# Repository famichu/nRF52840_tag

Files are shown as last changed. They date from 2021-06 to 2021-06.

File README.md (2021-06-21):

# nRF52840 tag

## What's this?

This is a development board works with coin batteries based on Adafruit Feather nRF52840 Express. This board works on all bootloaders of Adafruit Feather nRF52840 Express.

## Features

- Works with coin battery(CR2032)
- Extra battery(PH connector) support(Not suport charging)
- USB Type-C(USB 2.0)
- Warking same as Adafruit Feather nRF52840 Express(CircuitPython etc)
    - Programmable Full color LED(NeoPIXEL)
    - 1 usable push switch in program
    - 16MBit Flash memory

## How to use

1. Connect j-link and this board via SWD vias back side of this board.
2. Burn a bootloader you want to use with nrfjprog command.
    (For more detail, read "Burninng new Bootloader" on [adafruit's github](https://github.com/adafruit/Adafruit_nRF52_Arduino)

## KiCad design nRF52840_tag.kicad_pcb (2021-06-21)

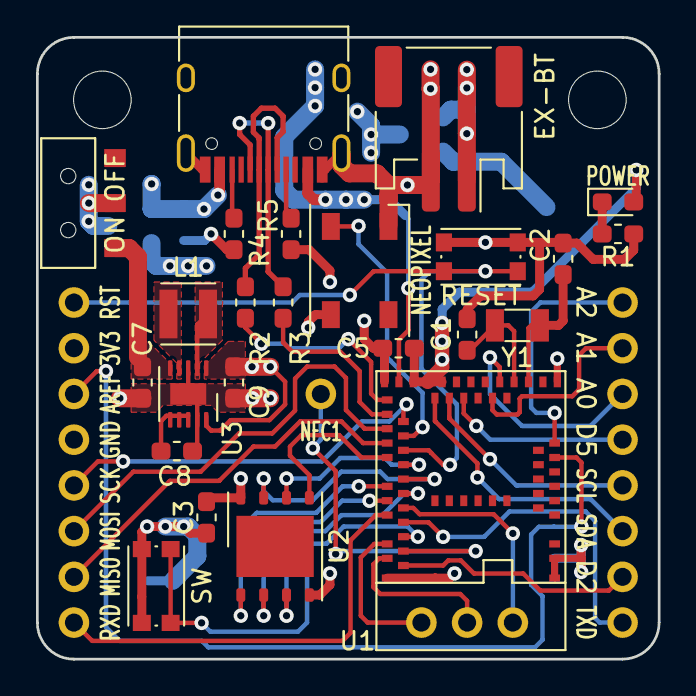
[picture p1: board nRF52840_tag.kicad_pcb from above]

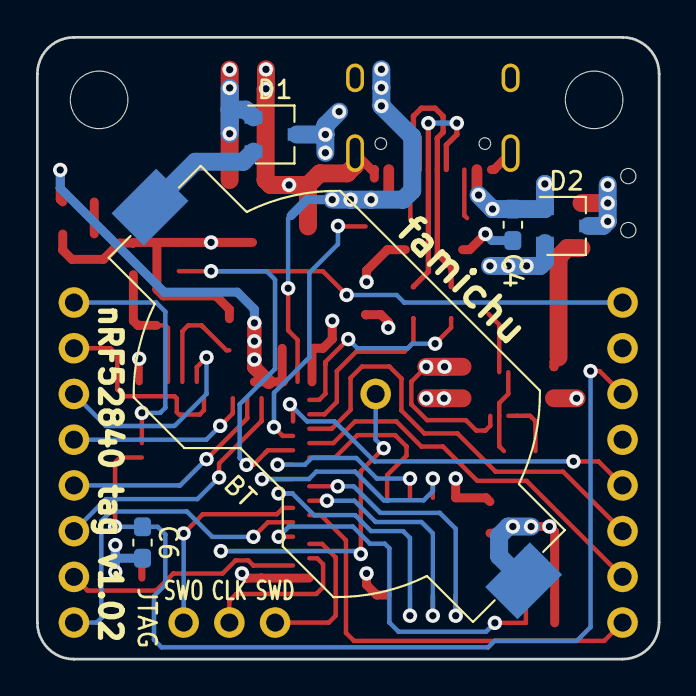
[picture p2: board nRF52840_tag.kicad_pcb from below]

Board: 4 copper layers, 34.5 x 34.5 mm, 35 parts (6 on the bottom side), 46 nets.

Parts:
BT: Battery_Cell; BatteryHolder_Keystone_1058_1x2032
C1, C2: 22pF; C_0603_1608Metric_Pad1.05x0.95mm_HandSolder
C3, C4, C7: 10uF; C_0603_1608Metric_Pad1.05x0.95mm_HandSolder
C5, C6, C8: 0.1uF; C_0603_1608Metric_Pad1.05x0.95mm_HandSolder
C9: 22uF; C_0603_1608Metric_Pad1.05x0.95mm_HandSolder
D1, D2: RB411D; SOT-23W
EX-BT: Conn_01x02; JST_PH_S2B-PH-SM4-TB_1x02-1MP_P2.00mm_Horizontal
H1, H2: MountingHole; MountingHole_3.2mm_M3
J1, J3: Conn_01x08; PinHeader_1x08_P2.54mm_Vertical
JTAG: Conn_01x03_Female; PinSocket_1x03_P2.54mm_Vertical
L1: L; L_Neosid_SMS-ME3015
NEOPIXEL: WS2812B; LED_WS2812B_PLCC4_5.0x5.0mm_P3.2mm
NFC1: Conn_01x01_Female; PinHeader_1x01_P2.54mm_Vertical
ON OFF: SW_SPDT; Slide_Switch_AYZ
P1: USB_C_Plug_USB2.0; USB_C_Receptacle_HRO_TYPE-C-31-M-12
POWER: POW; LED_0603_1608Metric_Pad1.05x0.95mm_HandSolder
R1: 1k; R_0603_1608Metric_Pad1.05x0.95mm_HandSolder
R2, R3: 22; R_0603_1608Metric_Pad1.05x0.95mm_HandSolder
R4, R5: 5.1k; R_0603_1608Metric_Pad1.05x0.95mm_HandSolder
RESET: SW_Push; SW_Push_1P1T_NO_CK_KMR2
SW: SW_Push; SW_Push_1P1T_NO_CK_KMR2
U1: MDBT50Q; MDBT50Q-1MV2
U2: GD25D10CT; WSON-8-1EP_6x5mm_P1.27mm_EP3.4x4.3mm
U3: TPS63031DSK; VSON-10-1EP_3x3mm_P0.5mm_EP1.2x2mm
Y1: 32.768; Crystal_SMD_3215-2Pin_3.2x1.5mm

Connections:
+3V3: C3.1, C5.1, C9.1, J1.2, NEOPIXEL.1, POWER.2, U1.28, U1.30, U1.31, U2.8, U3.1, U3.10
+BATT: D1.3, D2.2
/A0: J3.6, U1.20
/A1: J3.7, U1.21
/A2: J3.8, U1.14
/AREF: C6.1, J1.3, U1.12
/D2: J3.2, U1.54
/D5: J3.5, U1.25
/MISO: J1.7, U1.39
/MOSI: J1.6, U1.37
/NEOPIX: NEOPIXEL.4, U1.38
/NFC1: NFC1.1, U1.52
/QSPI_CS: U1.44, U2.1
/QSPI_DATA0: U1.41, U2.5
/QSPI_DATA1: U1.46, U2.2
/QSPI_DATA2: U1.45, U2.3
/QSPI_DATA3: U1.43, U2.7
/QSPI_SCK: U1.42, U2.6
/RESET: J1.1, RESET.2, U1.40
/RXD: J1.8, U1.48
/SCK: J1.5, U1.36
/SCL: J3.4, U1.27
/SDA: J3.3, U1.29
/SWCLK: JTAG.2, U1.53
/SWDIO: JTAG.3, U1.51
/SWITCH: SW.2, U1.50
/SWO: JTAG.1, U1.47
/TXD: J3.1, U1.49
/USBD+: R3.1, U1.35
/USBD-: R2.1, U1.34
GND: BT.2, C1.2, C2.2, C3.2, C4.2, C5.2, C6.2, C7.2, C8.2, C9.2, EX-BT.2, J1.4, NEOPIXEL.3, P1.A1, P1.A12, P1.B1, P1.B12, P1.S1, R1.1, R4.2, R5.2, RESET.1, SW.1, U1.1, U1.2, U1.15, U1.33, U1.55, U2.4, U3.3, U3.9, U3.11
unnamed: BT.1, D1.2
unnamed: C1.1, U1.18, Y1.1
unnamed: C2.1, U1.17, Y1.2
unnamed: C7.1, ON OFF.3, U3.5
unnamed: C8.1, U3.6, U3.7, U3.8
unnamed: D1.1, EX-BT.1
unnamed: D2.3, ON OFF.2
unnamed: L1.1, U3.4
unnamed: L1.2, U3.2
unnamed: P1.A5, R5.1
unnamed: P1.A6, P1.B6, R3.2
unnamed: P1.A7, P1.B7, R2.2
unnamed: P1.B5, R4.1
unnamed: POWER.1, R1.2
VBUS: C4.1, D2.1, P1.A4, P1.A9, P1.B4, P1.B9, U1.32
